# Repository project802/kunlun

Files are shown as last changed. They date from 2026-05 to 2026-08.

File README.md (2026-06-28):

# Kunlun Keyboard Repair and Upgrade

This repository contains documentation for repairing and upgrading the Kunlun keyboard from YDKB / KBDfans.

My Kunlun stopped functioning after one too many [ESD strikes](https://en.wikipedia.org/wiki/Electrostatic_discharge) approximately 3 years into ownership. The journey to create this documentation started because I wanted to bring my keyboard back to life, and there were no replacement parts.

The failure mode presented as "ghost" key presses. Pressing one key anywhere on the PCB with the failed shift register(s) would register many or all (depending on the duration of the keypress) keys from the same PCB.

As I began the repair, I realized that the design was not something I had seen before, nor was it one commonly seen in the mechanical keyboard community (for good reason, see the section below on shift registers). It is remarkably simple, and therefore remarkably easy to diagnose and repair.

## MCU Board Redesign

I have designed a replacement MCU board based on an STM32F072. For more information, [see the mcu board redesign folder](mcu%20board%20redesign/). Improvements include ESD support, an upgraded processor that allows for enabling all Vial features, and a speaker.

## Updated Firmware for Original MCU
During this process, I also ported the [original firmware written by YDKB](https://github.com/yangdigi/vial-qmk-v5/tree/ava) to the latest version of Vial. QMK has grown a lot since Kunlun was introduced, so it required some optimization and feature set choices to be made to fit within the microcontroller constraints. 

My port can be found here: https://github.com/project802/vial-qmk

A prebuilt image can be found in the [prebuilt binaries folder](prebuilt/).

To update the firmware:

- Rename firmware image to "kunlun.bin".
- Unplug the keyboard
- Press and hold the ESC key
- Plug in keyboard
- Copy (or drag and drop) the firmware image onto the storage device presented by the keyboard

## Keyboard Design

### Major Components

**Microcontroller - Atmel Mega32U4-AU** ([datasheet](https://github.com/project802/kunlun/blob/main/spec%20sheets/Atmel-7766-8-bit-AVR-ATmega16U4-32U4_Datasheet.pdf))

A basic 8-bit microcontroller that is commonly seen in keyboards that support QMK. KBDfans used the TQFP44 package and placed it on a small PCB just for the usb interface, power supply, and microcontroller.

Kunlun uses the internal oscillator and only operates at 8 MHz, as VCC is connected to a regulated 3.3V supply and 16 MHz would require > 4.5V.

**Shift Registers - 74HC595** ([datasheet](https://github.com/project802/kunlun/blob/main/spec%20sheets/FM%2074HC595A.pdf))

When is a 74HC595 not a 74HC595? When its the one used on this keyboard. Apparently, [FM](https://www.superchip.cn/frontEn/index) decided to usurp the identifier and make something that is almost the same, but isn't. It uses open drain outputs (instead of push/pull) and also doesn't have either a latch clock nor output enable. 

The part is available on [LCSC](https://www.lcsc.com/product-detail/C110383.html).

This drove almost the entirety of why I went on the reverse engineering journey. The faulty shift registers were replaced with standard parts, and the keyboard had the same failure symptoms. After much head scratching, I figured they had to be open drain outputs and searched Google to [find a Facebook post](https://www.facebook.com/groups/955185619738067/posts/1121342913122336/) and [an EEVblog thread](https://www.eevblog.com/forum/projects/when-is-a-74hc595-not-a-74hc595/) that confirmed my suspicion. 

### Theory of Operation

The matrix is scanned entirely using only 3 GPIO. 

- PB1 - Serial data clock
- PB2 - Right PCB input, pull-up enabled
- PB3 - Left PCB input, pull-up enabled OR serial data

Serial clock and data are sent to the left and right PCB in parallel.

All switches on the right PCB have one side tied to a unique shift register output, and the other to PB2.

All switches on the left PCB have one side tied to a unique shift register output, and the other to PB3 through a 2.2kOhm resistor.

The shift registers on each PCB are run in serial so that shifting the test bit goes through each output sequentially.

Pressing a key acts as a jumper between its corresponding shift register output with the appropriate microcontroller input. If the shift register output is open drain (the bit is set to one), voltage at the microcontroller is not affected and remain logically high. If the shift register output is driven low (the keypress test bit, zero) then it will pull down the appropriate microcontroller input.

**Scanning**

- The matrix scan starts with clocking in the keypress test bit, a zero, by driving PB3 low and pulsing the PB1 data clock. PB3 is turned around to an input with pull-up.
- Both PB2 and PB3 inputs are evaluated for a keypress.
- The keypress test bit is shifted down one position in the shift register banks by driving PB3 high, pulsing the PB1 clock, then turning PB3 back to an input with pull-up.
- The loop of evaluate and shift continues until all register outputs have been scanned: the greater of the left (32) and right (40) outputs is 40 iterations.

That's it. It is arguably slower than a typical row/col matrix, but it can still be completed in short order (optimized to approximately 350 microseconds in my port) so it doesn't present any meaningful lag as the USB HID interface runs on a 1 millisecond interval. As a result, the stock and ported firmware restrict the scan rate to no faster than 1 kHz.

## Diagnosing a failed board

The photos in this section display the behavior of stock firmware. My ported firmware has different waveforms and sequences.

In my case, the microcontroller appeared to have full function so my focus was on the left and right PCBs. 

The right PCB was the closest to where the final ESD strike occurred so that is also where I started checking. There was no visible physical damage, so the first tests were to probe the various pins on the shift registers.

Starting with the first register in the chain, U24, verify inputs on pins 11 (clock) and 14 (data). You should see something similar to below.

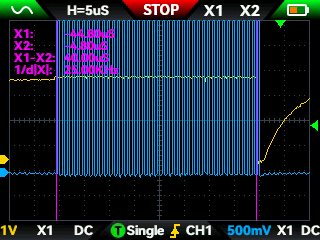
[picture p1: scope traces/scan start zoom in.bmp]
Scan Start


The data (yellow trace) can be seen driving low, clocked in, and slowly rising due to the weak pull-up.

Next, check pin 9 to make sure the IC is shifting the bit out and into the next one in the chain. In my case, this was part of the failure mode. It was not outputting anything but low so it was clocking in zeros to the next IC, so on and so forth, causing everything to look like it was pressed at the same time. 

Check the outputs of the shift register to make sure they are switching between open drain and driving low. You will need to press a key to connect the output to the pull-up within the micro, otherwise it will look like its driving low the entire time. It isn't! I also had this failure mode where the lines were driving low. It seems my IC had a dead data input internally and was always reading zeros so it latched those to the outputs and shifted it into the next in line.

A key pressed with its shift register output (yellow) and the bit clock (blue) is below.

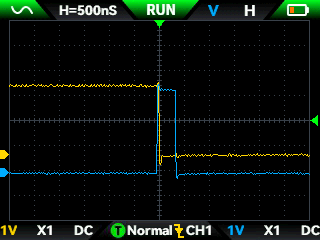
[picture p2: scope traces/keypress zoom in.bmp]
Good Keypress


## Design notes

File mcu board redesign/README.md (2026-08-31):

# Kunlun MCU Board Redesign

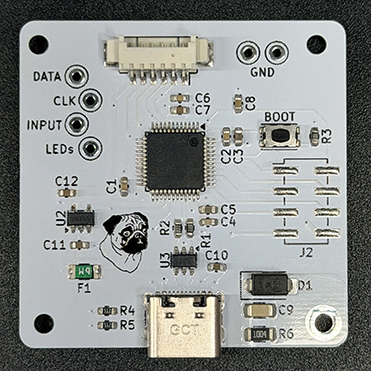
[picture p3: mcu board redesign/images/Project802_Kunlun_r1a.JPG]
Image of PCB


This is a redesign of the MCU board in the KBDFans Kunlun keyboard with the primary purpose of switching to an STM32F072 processor. The stock ATMega-based design is great, but the part is limited in code space and EEPROM to enable all of the modern Vial features. 

Improvements over the stock design:
* STM32F072 to enable all current Vial features
* Piezo speaker/buzzer
* ESD protection on USB
* Chassis grounding with ESD protection and static buildup mitigation

Otherwise, it reuses the same board geometry, mounting features, and connector locations as stock.

The pug is Moose. He was a good boy.

## Vial Support
### Prebuilt
A prebuilt binary can be found in the prebuilt folder: https://github.com/project802/kunlun/tree/main/prebuilt 

### Build from source
Download my fork of Vial here: https://github.com/project802/vial-qmk

Follow the normal Vial setup instructions. Build the binary with the command below:

        make project802/kunlun:vial

### Flashing
Flash as usual using the STM32 DFU mode.

## Design Files and BOM

Design files were made with KiCad 10. Full schematic and PCB are included.

The BOM is included in the [KiCad design files](kicad/), and as an export in the [production folder](kicad/production/). The export was done with JLCPCB's fabrication output plugin as I primarily use them as my fab house.

[Web-based interactive BOM and layout](https://htmlpreview.github.io/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) 

[Digikey Full BOM](https://www.digikey.com/en/mylists/list/4LIAA4M82M) - All components including debug features (~$15 USD) 

[Digikey Minimal BOM](https://www.digikey.com/en/mylists/list/V16MMQCCVU) - No debug features and no speaker (~$11 USD)

At the time of writing (5/2026), the cost for 5 boards with a nano coated and electropolished stencil to the US from JLCPCB was $21 USD. Boards alone are $5-$6 shipped.

### Manufacturing Data
FR4, 2 layers, 1.6mm thick, 1 oz copper

PCB Color: white with black silkscreen

## Pinout

*Functional Pins*

| Pin | Function |
|:---:|:---|
| PA0 | Matrix data / Left PCB input |
| PA1 | Matrix clock |
| PA2 | Right PCB input |
| PA3 | WS2812 LED data |
| PA8 | Speaker output |

*Optional / Debug Pins*

| Pin | Function |
|:---:|:---|
| PA13 | SWDIO |
| PA14 | SWCLK |
| PB3  | DEBUG_GPIO |
| PB6  | USART1_TX |
| PB7  | USART1_RX |
| PB15 | Speaker Alt (differential drive) |

*Debug Header*

| Pin | Function |
|:-:|:---|
| 1 | USART1_RX |
| 2 | NRST |
| 3 | DEBUG_GPIO |
| 4 | USART1_TX |
| 5 | VDD (3.3V) |
| 6 | SWCLK |
| 7 | SWDIO |
| 8 | VSS (GND) |

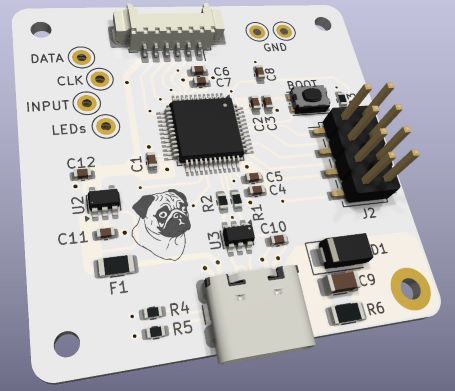
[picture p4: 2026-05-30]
mcu board redesign/images/pcb_projection.JPG

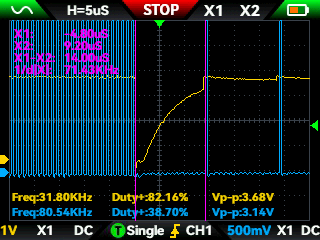
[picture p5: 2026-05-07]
scope traces/scan start.bmp

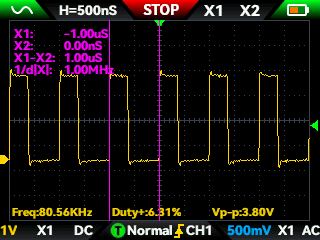
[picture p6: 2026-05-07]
scope traces/shift clock fast.bmp

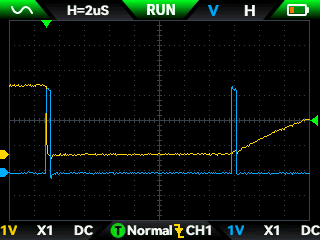
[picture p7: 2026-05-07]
scope traces/keypress.bmp

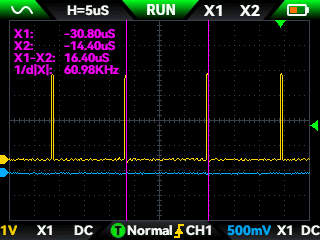
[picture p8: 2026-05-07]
scope traces/shift clock slow.bmp

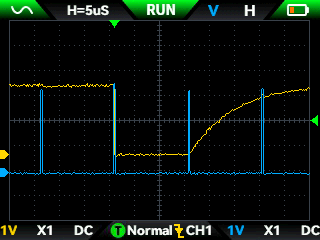
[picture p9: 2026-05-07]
scope traces/keypress zoom out.bmp

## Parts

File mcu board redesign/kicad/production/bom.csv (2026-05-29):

Designator | Footprint | Quantity | Value | LCSC Part #
C1, C2, C4, C8 | 0603 | 4 | 100nF | C14663
C10, C11, C12, C7 | 0603 | 4 | 1uF | C14663
C3, C5 | 0603 | 2 | 4.7uF | C14663
C6 | 0603 | 1 | 10nF | C57112
C9 | 1206 | 1 | 1nF | C9196
D1 | D_SMA | 1 | SMAJ5.0CA | C83324
F1 | 1206 | 1 | 500mA | C6964264
J1 | Molex_PicoBlade_53261-0671_1x06-1MP_P1.25mm_Horizontal | 1 | 0532610671 | C225115
J2 | PinHeader_2x04_P2.54mm_Vertical_SMD | 1 | 10129383-908001ALF | C49326142
J3 | USB_C_Receptacle_GCT_USB4105-xx-A_16P_TopMnt_Horizontal | 1 | USB4105-GF-A | C3020560
J4, J5, J6, J7 | TestPoint_Keystone_5000-5004_Miniature | 4 | 5002 | C238123
J8, J9 | TestPoint_Keystone_5000-5004_Miniature | 2 | 5001 | C238122
LS1 | Buzzer_CUI_CPT-9019S-SMT | 1 | Speaker | C95163
R1, R2 | 0603 | 2 | 22 | C23345
R3 | 0603 | 1 | 10k | C25804
R4, R5 | 0603 | 2 | 5.1k | C23186
R6 | 1206 | 1 | 1M | C17927
R7 | 0603 | 1 | 100 | C2479061
SW1 | SW_Push_1P1T_NO_CK_KMR2 | 1 | KMR231NG ULC LFS | C99271
U1 | LQFP-48_7x7mm_P0.5mm | 1 | STM32F072CBT6 | C81720
U2 | SOT-23-5 | 1 | AP2112K-3.3 | C51118
U3 | SOT-23-6 | 1 | USBLC6-2SC6 | C7519

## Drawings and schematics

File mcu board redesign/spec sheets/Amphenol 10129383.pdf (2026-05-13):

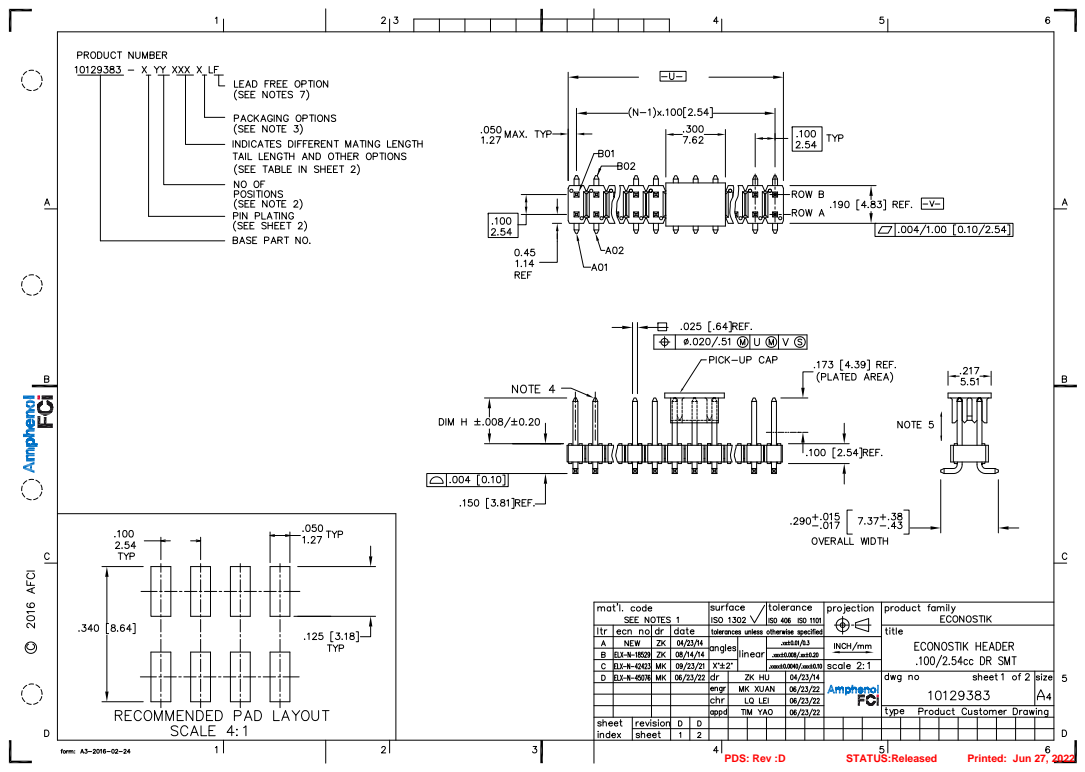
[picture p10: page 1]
PDS: Rev :D; STATUS:Released; Printed: Jun 27, 2022

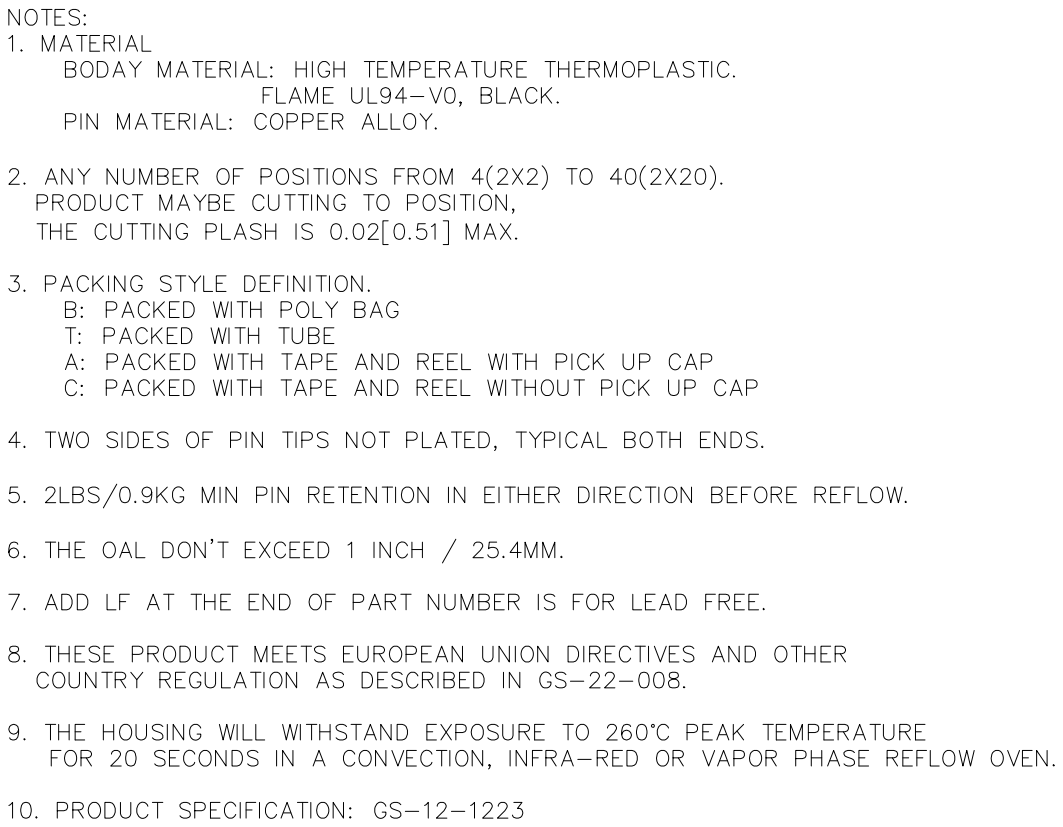
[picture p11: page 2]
PDS: Rev :D; STATUS:Released; Printed: Jun 27, 2022

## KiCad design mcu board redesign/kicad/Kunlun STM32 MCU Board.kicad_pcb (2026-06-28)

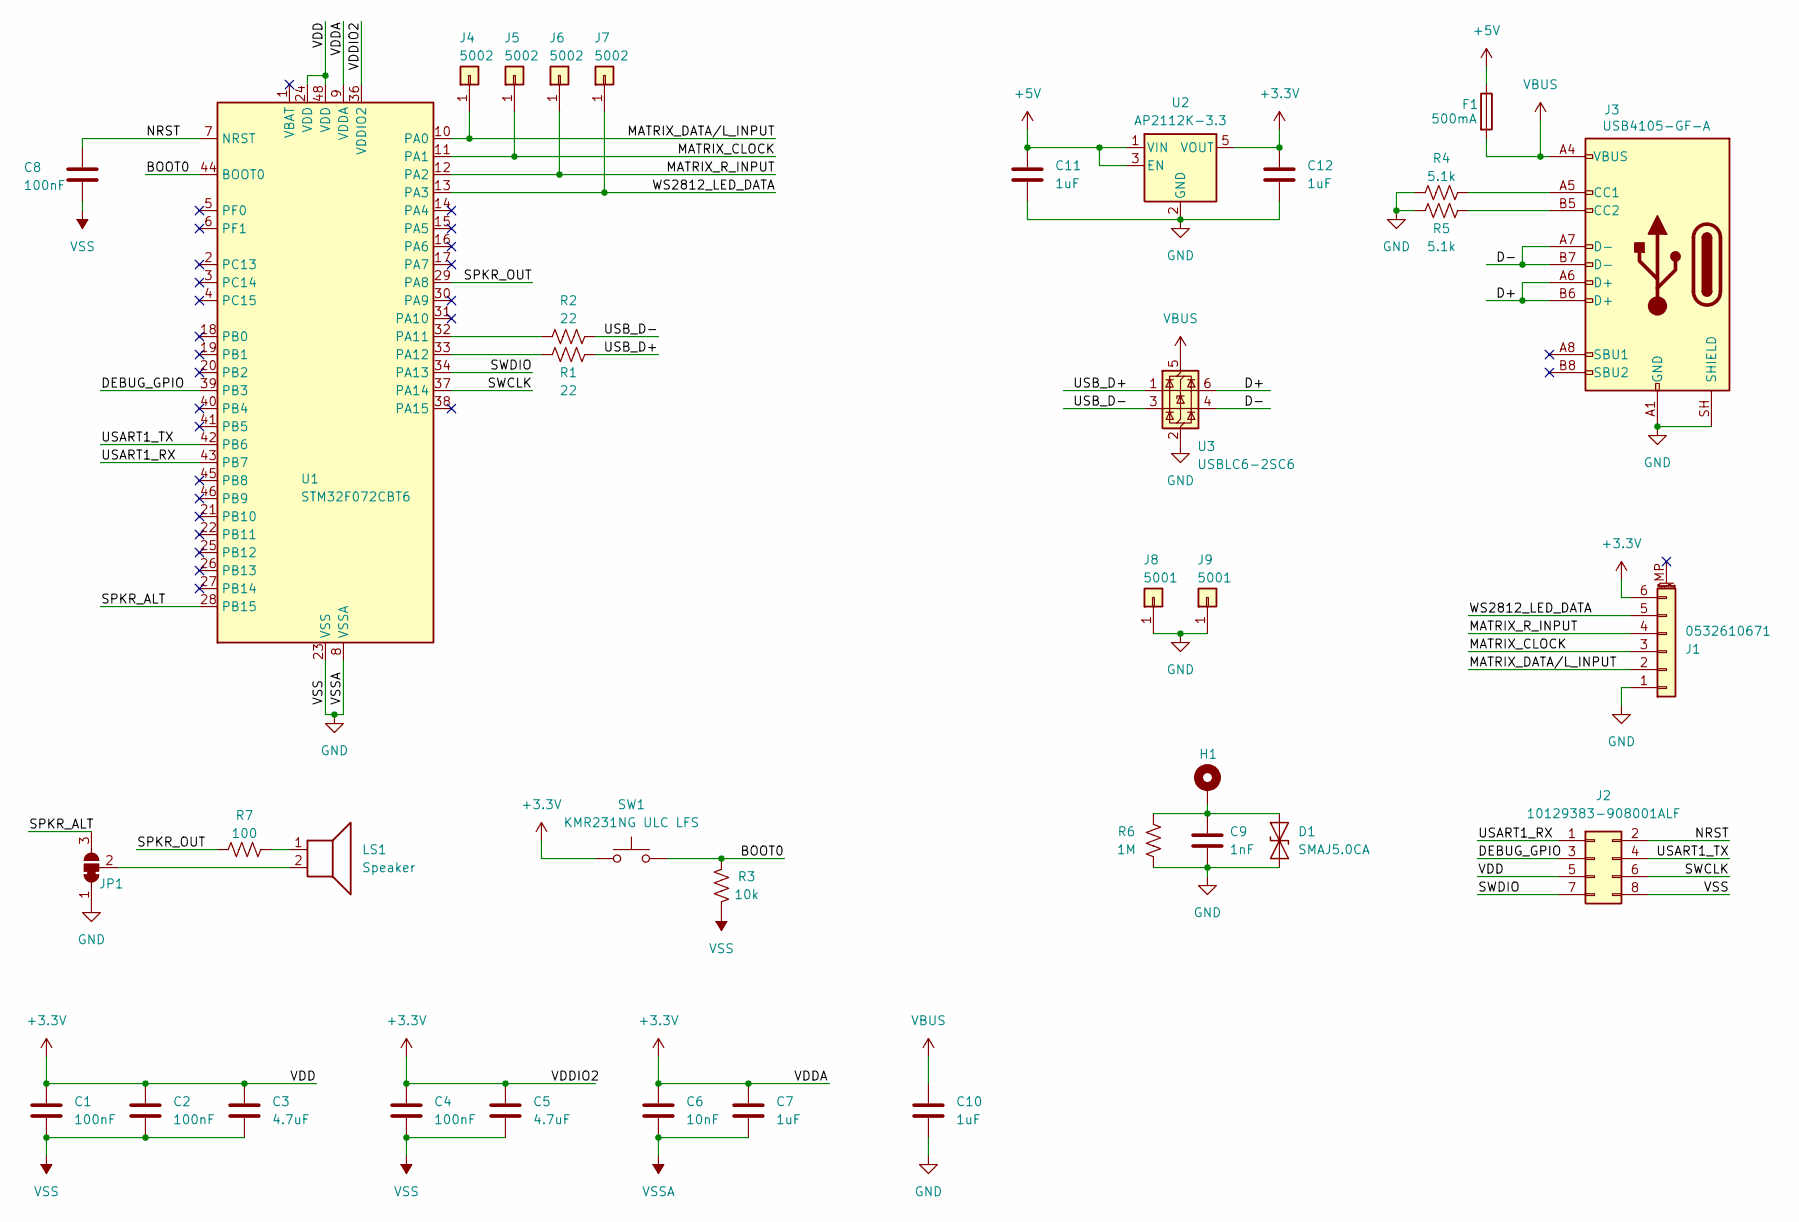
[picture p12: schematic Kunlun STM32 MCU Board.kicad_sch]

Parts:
C1, C2, C4, C8: 100nF; C_0603_1608Metric; Digikey 399-C0603C104K5RACTUCT-ND
C3, C5: 4.7uF; C_0603_1608Metric; Digikey 1276-2087-1-ND
C6: 10nF; C_0603_1608Metric; Digikey 399-C0603C103K5RACTUCT-ND
C7, C10, C11, C12: 1uF; C_0603_1608Metric; Digikey 399-C0603C105K4RACTUCT-ND
C9: 1nF; C_1206_3216Metric; Digikey 311-1489-1-ND
D1: SMAJ5.0CA; D_SMA; Digikey SMAJ5.0CALFCT-ND
F1: 500mA; Fuse_1206_3216Metric; Digikey 5923-0ZCJ0050FF2GCT-ND
H1: MountingHole_Pad; MountingHole_2.2mm_M2_Pad
J1: 0532610671; Molex_PicoBlade_53261-0671_1x06-1MP_P1.25mm_Horizontal; Digikey WM7624CT-ND
J2: 10129383-908001ALF; PinHeader_2x04_P2.54mm_Vertical_SMD; Digikey 609-10129383-908001ALFCT-ND
J3: USB4105-GF-A; USB_C_Receptacle_GCT_USB4105-xx-A_16P_TopMnt_Horizontal; Digikey 2073-USB4105-GF-ACT-ND
J4, J5, J6, J7: 5002; TestPoint_Keystone_5000-5004_Miniature; Digikey 36-5002-ND
J8, J9: 5001; TestPoint_Keystone_5000-5004_Miniature; Digikey 36-5001-ND
JP1: SolderJumper_3_Bridged12; SolderJumper-3_P1.3mm_Bridged12_RoundedPad1.0x1.5mm
LS1: Speaker; Buzzer_CUI_CPT-9019S-SMT; Digikey 102-3761-1-ND
R1, R2: 22; R_0603_1608Metric; Digikey RMCF0603FT22R0CT-ND
R3: 10k; R_0603_1608Metric; Digikey RMCF0603JT10K0CT-ND
R4, R5: 5.1k; R_0603_1608Metric; Digikey RMCF0603FT5K10CT-ND
R6: 1M; R_1206_3216Metric; Digikey RMCF1206FT1M00CT-ND
R7: 100; R_0603_1608Metric; Digikey RMCF0603FT100RCT-ND
SW1: KMR231NG ULC LFS; SW_Push_1P1T_NO_CK_KMR2; Digikey CKN10284CT-ND
U1: STM32F072CBT6; LQFP-48_7x7mm_P0.5mm; Digikey 497-14645-ND
U2: AP2112K-3.3; SOT-23-5; Digikey AP2112K-3.3TRG1DICT-ND
U3: USBLC6-2SC6; SOT-23-6; Digikey 497-5235-1-ND

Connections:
+3.3V: C1.1, C2.1, C3.1, C4.1, C5.1, C6.1, C7.1, C12.1, J1.6, J2.5, SW1.1, U1.9 (VDDA), U1.24 (VDD), U1.36 (VDDIO2), U1.48 (VDD), U2.5 (VOUT)
+5V: C11.1, F1.1, U2.1 (VIN), U2.3 (EN)
/BOOT0: R3.1, SW1.2, U1.44 (BOOT0)
/D+: J3.A6 (D+), J3.B6 (D+), U3.6 (I/O1)
/D-: J3.A7 (D-), J3.B7 (D-), U3.4 (I/O2)
/DEBUG_GPIO: J2.3, U1.39 (PB3)
/MATRIX_CLOCK: J1.3, J5.1 (Pin_1_1), U1.11 (PA1)
/MATRIX_DATA/L_INPUT: J1.2, J4.1 (Pin_1_1), U1.10 (PA0)
/MATRIX_R_INPUT: J1.4, J6.1 (Pin_1_1), U1.12 (PA2)
/NRST: C8.1, J2.2, U1.7 (NRST)
/SPKR_ALT: JP1.3 (B), U1.28 (PB15)
/SPKR_OUT: R7.2, U1.29 (PA8)
/SWCLK: J2.6, U1.37 (PA14)
/SWDIO: J2.7, U1.34 (PA13)
/USART1_RX: J2.1, U1.43 (PB7)
/USART1_TX: J2.4, U1.42 (PB6)
/USB_D+: R1.1, U3.1 (I/O1)
/USB_D-: R2.1, U3.3 (I/O2)
/WS2812_LED_DATA: J1.5, J7.1 (Pin_1_1), U1.13 (PA3)
GND: C1.2, C2.2, C3.2, C4.2, C5.2, C6.2, C7.2, C8.2, C9.2, C10.2, C11.2, C12.2, D1.1 (A1), J1.1, J2.8, J3.A1 (GND), J3.A12 (GND), J3.B1 (GND), J3.B12 (GND), J3.SH (SHIELD), J8.1 (Pin_1_1), J9.1 (Pin_1_1), JP1.1 (A), R3.2, R4.2, R5.1, R6.2, U1.8 (VSSA), U1.23 (VSS), U1.35 (VSS), U1.47 (VSS), U2.2 (GND), U3.2 (GND)
unnamed: C9.1, D1.2 (A2), H1.1 (1_1), R6.1
unnamed: J3.A5 (CC1), R4.1
unnamed: J3.B5 (CC2), R5.2
unnamed: JP1.2 (C), LS1.2
unnamed: LS1.1, R7.1
unnamed: R2.2, U1.32 (PA11)
unnamed: R1.2, U1.33 (PA12)
VBUS: C10.1, F1.2, J3.A4 (VBUS), J3.A9 (VBUS), J3.B4 (VBUS), J3.B9 (VBUS), U3.5 (VBUS)

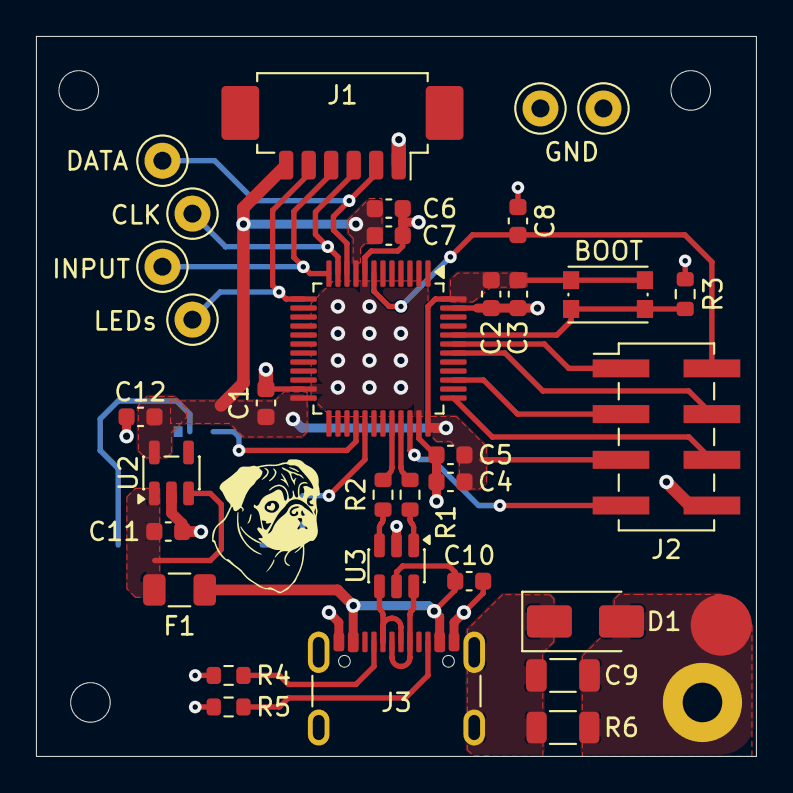
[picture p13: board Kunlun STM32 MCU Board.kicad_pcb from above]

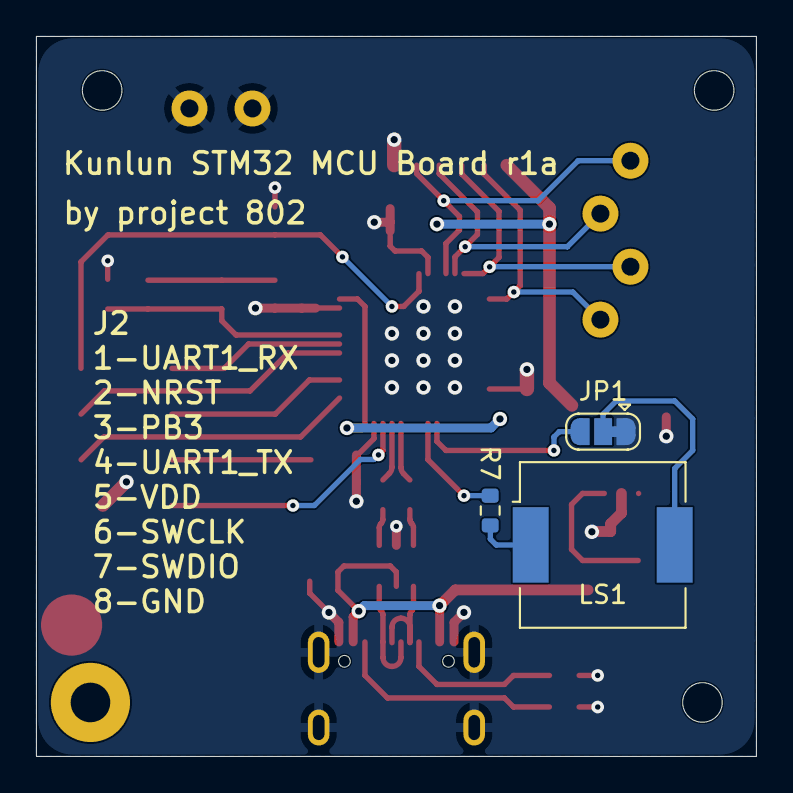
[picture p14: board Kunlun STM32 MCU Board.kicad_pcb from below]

Board: 2 copper layers, 40.0 x 40.0 mm, 37 parts (3 on the bottom side), 28 nets.

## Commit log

2026-05-13 Initial MCU redesign commit
    [Kunlun STM32 MCU Board.kicad_pcb, Kunlun STM32 MCU Board.kicad_sch]
2026-05-15 Lots of updates
    Add ESD protection R6/C9
    Layout changes for bypass caps
    Layout changes to pass all JLC DFM checks
    Fill out J2 and optimize routing
    [Kunlun STM32 MCU Board.kicad_pcb, Kunlun STM32 MCU Board.kicad_sch]
2026-05-15 Initial BOM
    [Kunlun STM32 MCU Board BOM.csv]
2026-05-16 Mostly layout updates
    Add VBUS decoupling cap.
    Rearrange traces for less ground plane chops and fewer vias.
    Move some components around for trace optimization (boot switch, etc)
    Tweak the decoupling caps
    Remove pads from 3 mounting holes to avoid potential chassis ground loops
    [Kunlun STM32 MCU Board.kicad_pcb, Kunlun STM32 MCU Board.kicad_sch]
2026-05-16 Make D- pretty at the connector
    [Kunlun STM32 MCU Board.kicad_pcb]
2026-05-16 More pretty things
    Curve the fill around chassis ground mounting hole.
    Label switch as "BOOT"
    Pretty up R4
    Small trace tweaks
    [Kunlun STM32 MCU Board.kicad_pcb]
2026-05-16 Pretty up traces to J1
    [Kunlun STM32 MCU Board.kicad_pcb]
2026-05-16 Fatten up NRST going to the pin on U1
    [Kunlun STM32 MCU Board.kicad_pcb]
2026-05-16 Added speaker, changed fuse.
    [Kunlun STM32 MCU Board.kicad_pcb, Kunlun STM32 MCU Board.kicad_sch]
2026-05-16 Slide power section closer to MCU
    And associated layout tweaks
    [Kunlun STM32 MCU Board.kicad_pcb]
2026-05-16 Set correct PartNo for R7
    [Kunlun STM32 MCU Board.kicad_sch]
2026-05-20 Add a TVS to ESD circuit
    [Kunlun STM32 MCU Board.kicad_pcb, Kunlun STM32 MCU Board.kicad_sch]
2026-05-22 Add LCSC part numbers
    [Kunlun STM32 MCU Board.kicad_pcb, Kunlun STM32 MCU Board.kicad_sch]
2026-05-22 Update part numbers
    Found alternates in LCSC that are "basic" instead of "extended" so manufacturing is considerably less expensive (saved $30 in setup costs).
    Digikey is out of the AP2112 so list the AP7365 as an alternate.
    [Kunlun STM32 MCU Board.kicad_pcb, Kunlun STM32 MCU Board.kicad_sch]
2026-05-29 Move one trace a bit for cosmetics
    [Kunlun STM32 MCU Board.kicad_pcb]
2026-05-29 Move D1, C9, R4/5/6 for JLCPCB DFM
    [Kunlun STM32 MCU Board.kicad_pcb]
2026-05-29 First production order (PCB and stencil only, no assembly)
    [bom.csv, designators.csv, positions.csv]
2026-05-30 Add prebuilt binary for Kunlun stock MCU board
2026-06-14 Fix rear mounting hole locations
    [Kunlun STM32 MCU Board.kicad_pcb]
2026-06-28 Set rev to 1a
    It was set to 2 but there were other changes planned that I didn't keep.
    [Kunlun STM32 MCU Board.kicad_pcb]
2026-06-28 Compatible with rev 1 and 1a
    Full user functionality enabled and tested for a couple of weeks. Looks good.
2026-06-28 Update README with manufacturing data and cost details
    Added manufacturing data and updated cost details for boards.
2026-08-31 Add interactive KiCad BOM HTML export
